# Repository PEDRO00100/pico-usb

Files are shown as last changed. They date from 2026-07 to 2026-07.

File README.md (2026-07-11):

> [!WARNING]
> ### ⚠️ LEGAL DISCLAIMER & TERMS OF USE
> 
> This hardware device, firmware, and its accompanying software suite are developed and provided **strictly for educational purposes, authorized laboratory environments, and professional security auditing.**
> 
> By building, accessing, or utilizing this tool, you acknowledge and agree to the following:
> 
> * **Authorized Use Only:** You must obtain explicit, written consent from the infrastructure or system owner before engaging in any security testing, payload injection, or assessment.
> * **No Liability:** The creators, contributors, and maintainers of this project assume **absolute no liability** and are not responsible for any direct or indirect damage, data loss, misuse, or illegal activities resulting from the deployment of this device.
> * **End-User Responsibility:** It is solely your responsibility to ensure compliance with all applicable local, state, and federal laws. Any use of this tool for malicious intent, unauthorized access, or covert data exfiltration is strictly prohibited.

## ⚙️ System Architecture & Operation

This project is a hardware-based security auditing and penetration testing tool (HID Injection Engine) built around the **RP2040** microcontroller. Unlike traditional USB injection scripts that require hardcoding and recompiling firmware for every assessment, this device operates as an autonomous, dynamic execution engine. It reads attack scripts directly from an external MicroSD card and allows instant, on-the-fly selection of up to 16 different payloads via hardware switching.

---

### 1. Hardware & Peripheral Mapping

The PCB layout is engineered for signal integrity, prioritizing short trace lengths for high-speed SPI bus lines while keeping digital control switches isolated. The GPIO pin assignment on the RP2040 is structured as follows:

| Physical Peripheral | RP2040 Pin | System Function / Role | Electrical Logic |
| :--- | :---: | :--- | :--- |
| **Setup Mode Switch (`GP0/DEV`)** | `GP0` | Toggles between Development Mode & Attack Mode | Internal Pull-Up (`GND = Dev`) |
| **DIP Switch (Bit 0 - LSB)** | `GP2` | Binary Payload Selector (`payload1Pin` / `SWD-1`) | Active-Low (`GND = 1`) |
| **DIP Switch (Bit 1)** | `GP3` | Binary Payload Selector (`payload2Pin` / `SWD-2`) | Active-Low (`GND = 1`) |
| **DIP Switch (Bit 2)** | `GP4` | Binary Payload Selector (`payload3Pin` / `SWD-3`) | Active-Low (`GND = 1`) |
| **DIP Switch (Bit 3 - MSB)** | `GP5` | Binary Payload Selector (`payload4Pin` / `SWD-4`) | Active-Low (`GND = 1`) |
| **MicroSD SPI (MISO)** | `GP16` | Data receive from external storage | SPI0 Bus |
| **MicroSD SPI (CS)** | `GP17` | Chip Select / SD card activation | Digital Output |
| **MicroSD SPI (SCK)** | `GP18` | Bus clock synchronization | SPI0 Bus |
| **MicroSD SPI (MOSI)** | `GP19` | Data transmit to external storage | SPI0 Bus |

*(Note: Additional GPIO pins such as `GP22` are routed on the PCB layout for secondary applications or future expansion, but are omitted from active execution loops to streamline automated payload delivery).*

#### 🔘 Onboard Physical Control Buttons
The device incorporates three dedicated tactile buttons for system management and firmware operations:
* **`BOOTSEL` Button:** Connected directly to the RP2040 bootrom interface. Holding this button while plugging the device into a host forces entry into USB Mass Storage bootloader mode for flashing or updating the core CircuitPython firmware (`.uf2` files).
* **`RUN` / `RST` Button:** Triggers a hard electrical reset of the RP2040 microcontroller without needing to physically unplug the USB connector, enabling rapid rebooting after switching payloads.
* **`DEV MODE` Button (`GP0`):** Pulls `GP0` to ground (`GND`). When engaged during boot, it prevents automated payload execution and mounts the internal `CIRCUITPY` drive for safe script editing.

#### 🔌 Dual-Head USB Interface & Protection
The hardware features a versatile **Dual-Head USB architecture**, integrating both **USB-A** and **USB-C** connectors directly onto the PCB edge. This allows native insertion into legacy desktops, modern laptops, servers, and mobile devices without requiring external adapters. 
* **ESD Protection:** The data lines (`D+` / `D-`) include onboard electrical protections and transient voltage suppression to safeguard the microcontroller against static discharges during rapid field insertion.
* **⚠️ Critical Safety Rule:** The dual connectors share the same internal USB data bus. **Never connect both USB-A and USB-C ports simultaneously to two different host devices or power sources**, as this could cause bus contention or electrical back-feeding.

---

### 2. Binary Payload Selector (4-Bit DIP Switch)

To eliminate the need for reprogramming the device between different engagement scenarios, the board features an onboard 4-position DIP switch (`A6H-4101`) operating on **pure binary decoding**.

Each switch pin is configured with internal pull-up resistors (Active-Low logic). Moving a switch to the **ON** position bridges the circuit to Ground (`GND`), which the firmware decodes as a logical `1` for that specific bit position.

```text
Bit 3 (MSB)   Bit 2       Bit 1       Bit 0 (LSB)
  [GP5]       [GP4]       [GP3]       [GP2]
  Value: 8    Value: 4    Value: 2    Value: 1

```

* **Combination `0000` (All OFF):** Executes the default script located at `/sd/payload.dd`.
* **Combinations `0001` through `1111` (1 to 15):** Sums the active bit values in powers of 2 and dynamically routes execution to the numbered script on the MicroSD card (from `/sd/payload1.dd` up to `/sd/payload15.dd`).

---

### 3. Operating Modes & USB Stealth Spoofing

The USB enumeration profile is strictly managed by `boot.py` **before** the target operating system (Windows, macOS, or Linux) initializes the peripheral. The operating mode is governed by the state of the `GP0` tactile button/switch:

#### 🟢 Development Mode (`GP0` connected to GND)

* **Purpose:** Script editing, live debugging, and system maintenance.
* **USB Profile:** Habilitates standard USB Mass Storage (exposing the internal `CIRCUITPY` drive), Serial CDC (REPL console), and HID keyboard interfaces. Automated attack execution is safely bypassed.

#### 🔴 Attack / Stealth Mode (`GP0` floating / Unpressed)

* **Purpose:** Active field auditing and Endpoint Detection & Response (EDR / DLP) evasion.
* **USB Profile:** The firmware executes `storage.disable_usb_drive()`, completely hiding internal Flash memory from the host OS and disabling Serial/MIDI endpoints (`usb_cdc.disable()`, `usb_midi.disable()`).
* **Identity Spoofing:** To prevent triggering vendor-specific blocklists while adhering to safe open-source distribution standards (BYOC - *Bring Your Own Configuration*), the device overrides its hardware descriptors using the open community VID **`0x1209`** (pid.codes) and generic keyboard PID **`0x0001`**:

```python
# Hardware descriptor override defined in boot.py
supervisor.set_usb_identification(
    vid=0x1209,         # Open-Source Community VID (pid.codes)
    pid=0x0001,         # Generic Keyboard PID
    manufacturer="Generic",
    product="USB Keyboard"
)

```

> ⚠️ **Tactical Advantage:** When plugged into a host system in Attack Mode, the operating system **strictly enumerates a generic HID USB Keyboard**. No storage drives are mounted, no COM ports appear in Device Manager, and no Raspberry Pi / Adafruit hardware signatures are exposed.

---

### 4. Asynchronous Execution Engine & Resilience

The core execution engine (`code.py`) is built around asynchronous event loops (`asyncio`). This allows the microcontroller to handle concurrent background tasks—such as button debouncing, filesystem polling, and monitoring host keyboard lock LEDs (Caps/Num/Scroll Lock) for data exfiltration—without causing latency or blocking keystroke injection.

To guarantee field reliability and prevent kernel panics during live deployments, the firmware implements multiple defensive architecture layers:

1. **Zero-RAM Allocation Filesystem Polling:** To check for the presence of payload files on the MicroSD card without fragmenting the microcontroller's limited heap memory, the engine avoids memory-heavy directory listings (`os.listdir()`). Instead, it performs direct, low-overhead FAT32 metadata queries using `os.stat()`.
2. **3-Tier Fallback Routing:** If an indexed script cannot be read, the execution pipeline gracefully degrades through three safety tiers to ensure the assessment does not fail silently:
* *Tier 1:* Attempts to execute the exact binary path selected by the DIP switch (e.g., `/sd/payload5.dd`).
* *Tier 2:* If the target file is missing, it falls back automatically to the standard default script (`/sd/payload.dd`).
* *Tier 3:* If the default script is also missing, it performs an emergency scan of the MicroSD card root and executes the first available `.dd` payload found.

3. **Hardware Kill-Switch:** During the boot sequence, if the engine detects a file named `loot.bin` in the root directory, it immediately aborts all keystroke injection routines to prevent accidental exfiltration overrides or execution loops.

## 💾 Firmware & Software Installation Guide

Setting up the device is divided into two straightforward phases: flashing the base interpreter (CircuitPython) and loading the attack and decoding engine. Once this process is complete, the microcontroller's execution logic will be permanently configured.

---

### Step 1: Installing the Core Engine (CircuitPython)

To enable the RP2040 microcontroller to interpret attack scripts in real time, you must install the base CircuitPython firmware:

1. **Bootloader Mode:** Press and hold the onboard **`BOOTSEL`** physical button while plugging the USB cable into your computer.
2. **RPI-RP2 Drive:** Release the button once plugged in. Your operating system will automatically mount a mass storage drive named `RPI-RP2`.
3. **Flashing:** Download the latest official release of **CircuitPython 10.x** (`.uf2` file format) for the Raspberry Pi Pico / RP2040 and drag the file directly into the `RPI-RP2` drive.
4. **Automatic Reboot:** Once the copy completes, the drive will automatically eject, and the microcontroller will reboot, creating a new flash drive named **`CIRCUITPY`**.

---

### Step 2: Loading the Attack Engine & Dependencies

Once the `CIRCUITPY` drive is available, you must transfer the core operating logic and hardware libraries. Navigate to the `Software/` directory within this repository, which contains the exact system package:

```text
Software/
├── boot.py             # Hardware USB Profile & Stealth Spoofing Manager
├── boot_out.txt        # System boot log (Auto-generated by CircuitPython)
├── code.py             # Asynchronous Core Kernel & Execution Loop
├── duckyinpython.py    # DuckyScript Parser & Payload Execution Engine
├── lib/                # Required CircuitPython libraries (HID, Debouncer, etc.)
├── LICENSE             # GPLv2 License
├── pins.py             # Hardware GPIO Pin Mapping & DIP Switch Config
├── sd/                 # Example payload directory (For external MicroSD card)
└── settings.toml       # Runtime configuration file

```

#### 📦 File Transfer Protocol:

1. **Internal Flash (`CIRCUITPY` drive):**
* Select and copy all core Python scripts (`boot.py`, `code.py`, `duckyinpython.py`, `pins.py`, `settings.toml`, and `LICENSE`).
* **⚠️ CRITICAL - The `lib/` folder:** You **must** copy the entire **`lib/`** directory into the root of the `CIRCUITPY` drive. This folder contains essential drivers (`adafruit_hid`, `adafruit_debouncer`, etc.) required for keystroke injection and tactile button reading.
* *(Note: You can ignore `boot_out.txt`, as the microcontroller will automatically regenerate this log file on its next boot).*

2. **External Storage (MicroSD Card):**
* Take the contents inside the **`sd/`** folder (e.g., your `.dd` payload files) and copy them directly to the root of your FAT32-formatted **MicroSD card**.
* Insert the MicroSD card into the onboard SPI slot (`J3`). When the RP2040 boots, `code.py` will automatically mount this physical card at the `/sd` system path.

---

### Step 3: Access Management & Safe Mode (Critical!)

As soon as the system files are copied over, `boot.py` will take absolute control of the board's USB interfaces on every subsequent boot. It is crucial to understand the following tactical behavior before unplugging the cable:

> 🚨 **AUTOMATIC INJECTION WARNING:**
> From this moment forward, **every time you plug the device into a USB port normally, it will boot in Attack Mode (Stealth Mode)**. This means the `CIRCUITPY` drive will completely disappear from your operating system, and the payload selected via the DIP switch on the MicroSD card **will execute automatically and immediately**.

#### 🛠️ How to re-access the `CIRCUITPY` drive to edit code?

To prevent the attack script from triggering and to mount the internal storage drive back onto your computer (e.g., to debug code or update core scripts), you must engage the hardware safety override:

1. **Press and hold the `DEV MODE` (`GP0`) button** on the board.
2. While holding the button down, **plug the USB cable** into your computer.
3. Once plugged in, you can safely release the button.
4. **Result:** The microcontroller detects the ground connection on pin `GP0`, aborts automated payload execution, and safely exposes the `CIRCUITPY` drive and Serial REPL console on your screen in safe development mode.

## 🛠️ Hardware Compatibility & DIY Protoboard Build

While this project features a custom-designed, dedicated PCB with integrated dual-head USB connectors and ESD protection, the core software suite is **100% compatible with standard, off-the-shelf Raspberry Pi Pico** boards (or any generic RP2040 development board running CircuitPython).

If you are prototyping on a breadboard or building a custom DIY injection tool using an original Raspberry Pi Pico, you can deploy this firmware without modifying a single line of code. You simply need to manually wire the external modules according to the hardware mapping defined in `pins.py`:

### 📌 DIY Wiring Checklist for Standard Pico:
* **MicroSD Card Module:** Wire a 3.3V SPI MicroSD breakout board directly to the RP2040's **SPI0 bus** (`MISO` -> `GP16`, `CS` -> `GP17`, `SCK` -> `GP18`, and `MOSI` -> `GP19`).
* **4-Bit Binary DIP Switch:** Connect four mechanical switches (or simple jumper wires) between ground (`GND`) and pins **`GP2`**, **`GP3`**, **`GP4`**, and **`GP5`**. When closed (grounded), the internal pull-up resistor drops to `0V`, which the software decodes as an active binary `1`.
* **Development Mode Safety Jumper (`GP0`):** You **must** wire a tactile button or jumper wire between **`GP0`** and **`GND`**. This is critical: without this physical override, an off-the-shelf Pico will permanently boot in Stealth Attack Mode, hiding the USB drive and locking you out of the REPL console.

---

## 📂 MicroSD Payload Structure & Binary Mapping

The execution engine searches the root directory of the FAT32-formatted MicroSD card for standard DuckyScript (`.dd`) payload files. To utilize the hardware DIP switch, name your scripts following this exact binary convention:

| DIP Switch State (`SW4` -> `SW1`) | Binary Value | Target Payload Path | Description / Engagement Use Case |
| :---: | :---: | :--- | :--- |
| `OFF` · `OFF` · `OFF` · `OFF` | `0000` (0) | `/sd/payload.dd` | Default fallback / Standard assessment payload |
| `OFF` · `OFF` · `OFF` · `ON`  | `0001` (1) | `/sd/payload1.dd` | Quick reconnaissance / System info enumeration |
| `OFF` · `OFF` · `ON`  · `OFF` | `0010` (2) | `/sd/payload2.dd` | Remote access staging / Reverse shell |
| `...` · `...` · `...` · `...` | `1 to 14`  | `/sd/payload3.dd` to `14.dd` | Custom specialized audit scripts |
| `ON`  · `ON`  · `ON`  · `ON`  | `1111` (15)| `/sd/payload15.dd`| Emergency cleanup / Anti-forensic routine |

> 💡 **Tactical Fallback Note:** If you dial a specific binary combination on the DIP switch (e.g., index `5`) but forget to load `/sd/payload5.dd` onto the MicroSD card, the asynchronous engine will not crash. It automatically downgrades to Tier-2 fallback and executes `/sd/payload.dd`, guaranteeing that your field engagement never fails silently.

---

## 📸 Board Designs & Renders

3D renders and PCB layer routing for the **Pico-USB** board.

<table align="center">
  <tr>
    <td align="center">
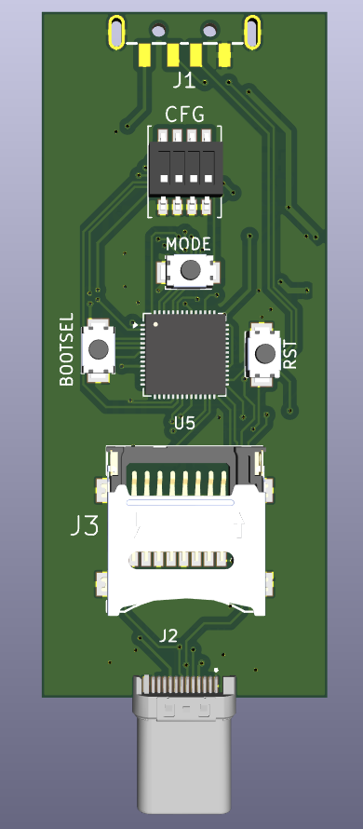
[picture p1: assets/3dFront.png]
3D Front View
      <br/>
      <sub><b>3D Front</b></sub>
    </td>
    <td align="center">
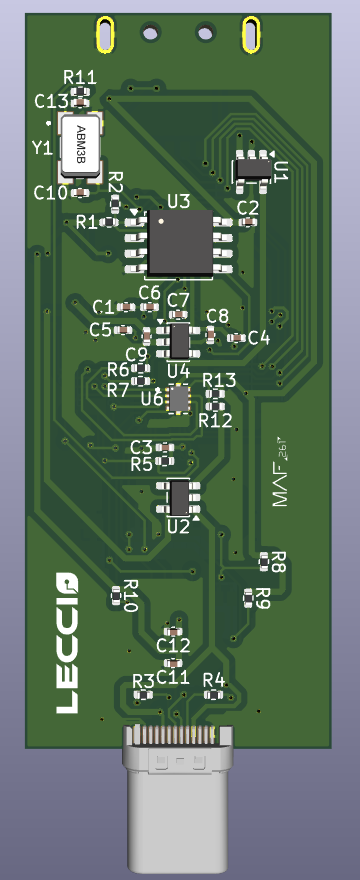
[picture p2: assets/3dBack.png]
3D Back View
      <br/>
      <sub><b>3D Back</b></sub>
    </td>
    <td align="center">
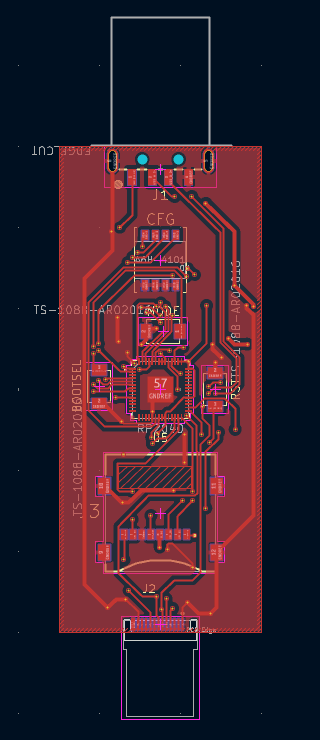
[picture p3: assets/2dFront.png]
2D Front Routing (F.Cu)
      <br/>
      <sub><b>2D F.Cu</b></sub>
    </td>
    <td align="center">
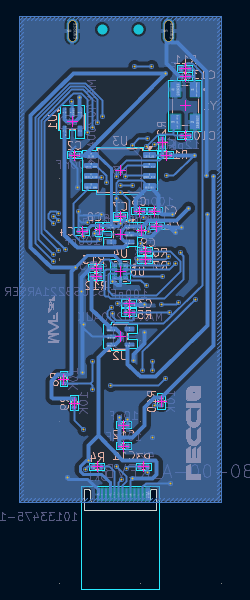
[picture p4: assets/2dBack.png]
2D Back Routing (B.Cu)
      <br/>
      <sub><b>2D B.Cu</b></sub>
    </td>
  </tr>
</table>

---

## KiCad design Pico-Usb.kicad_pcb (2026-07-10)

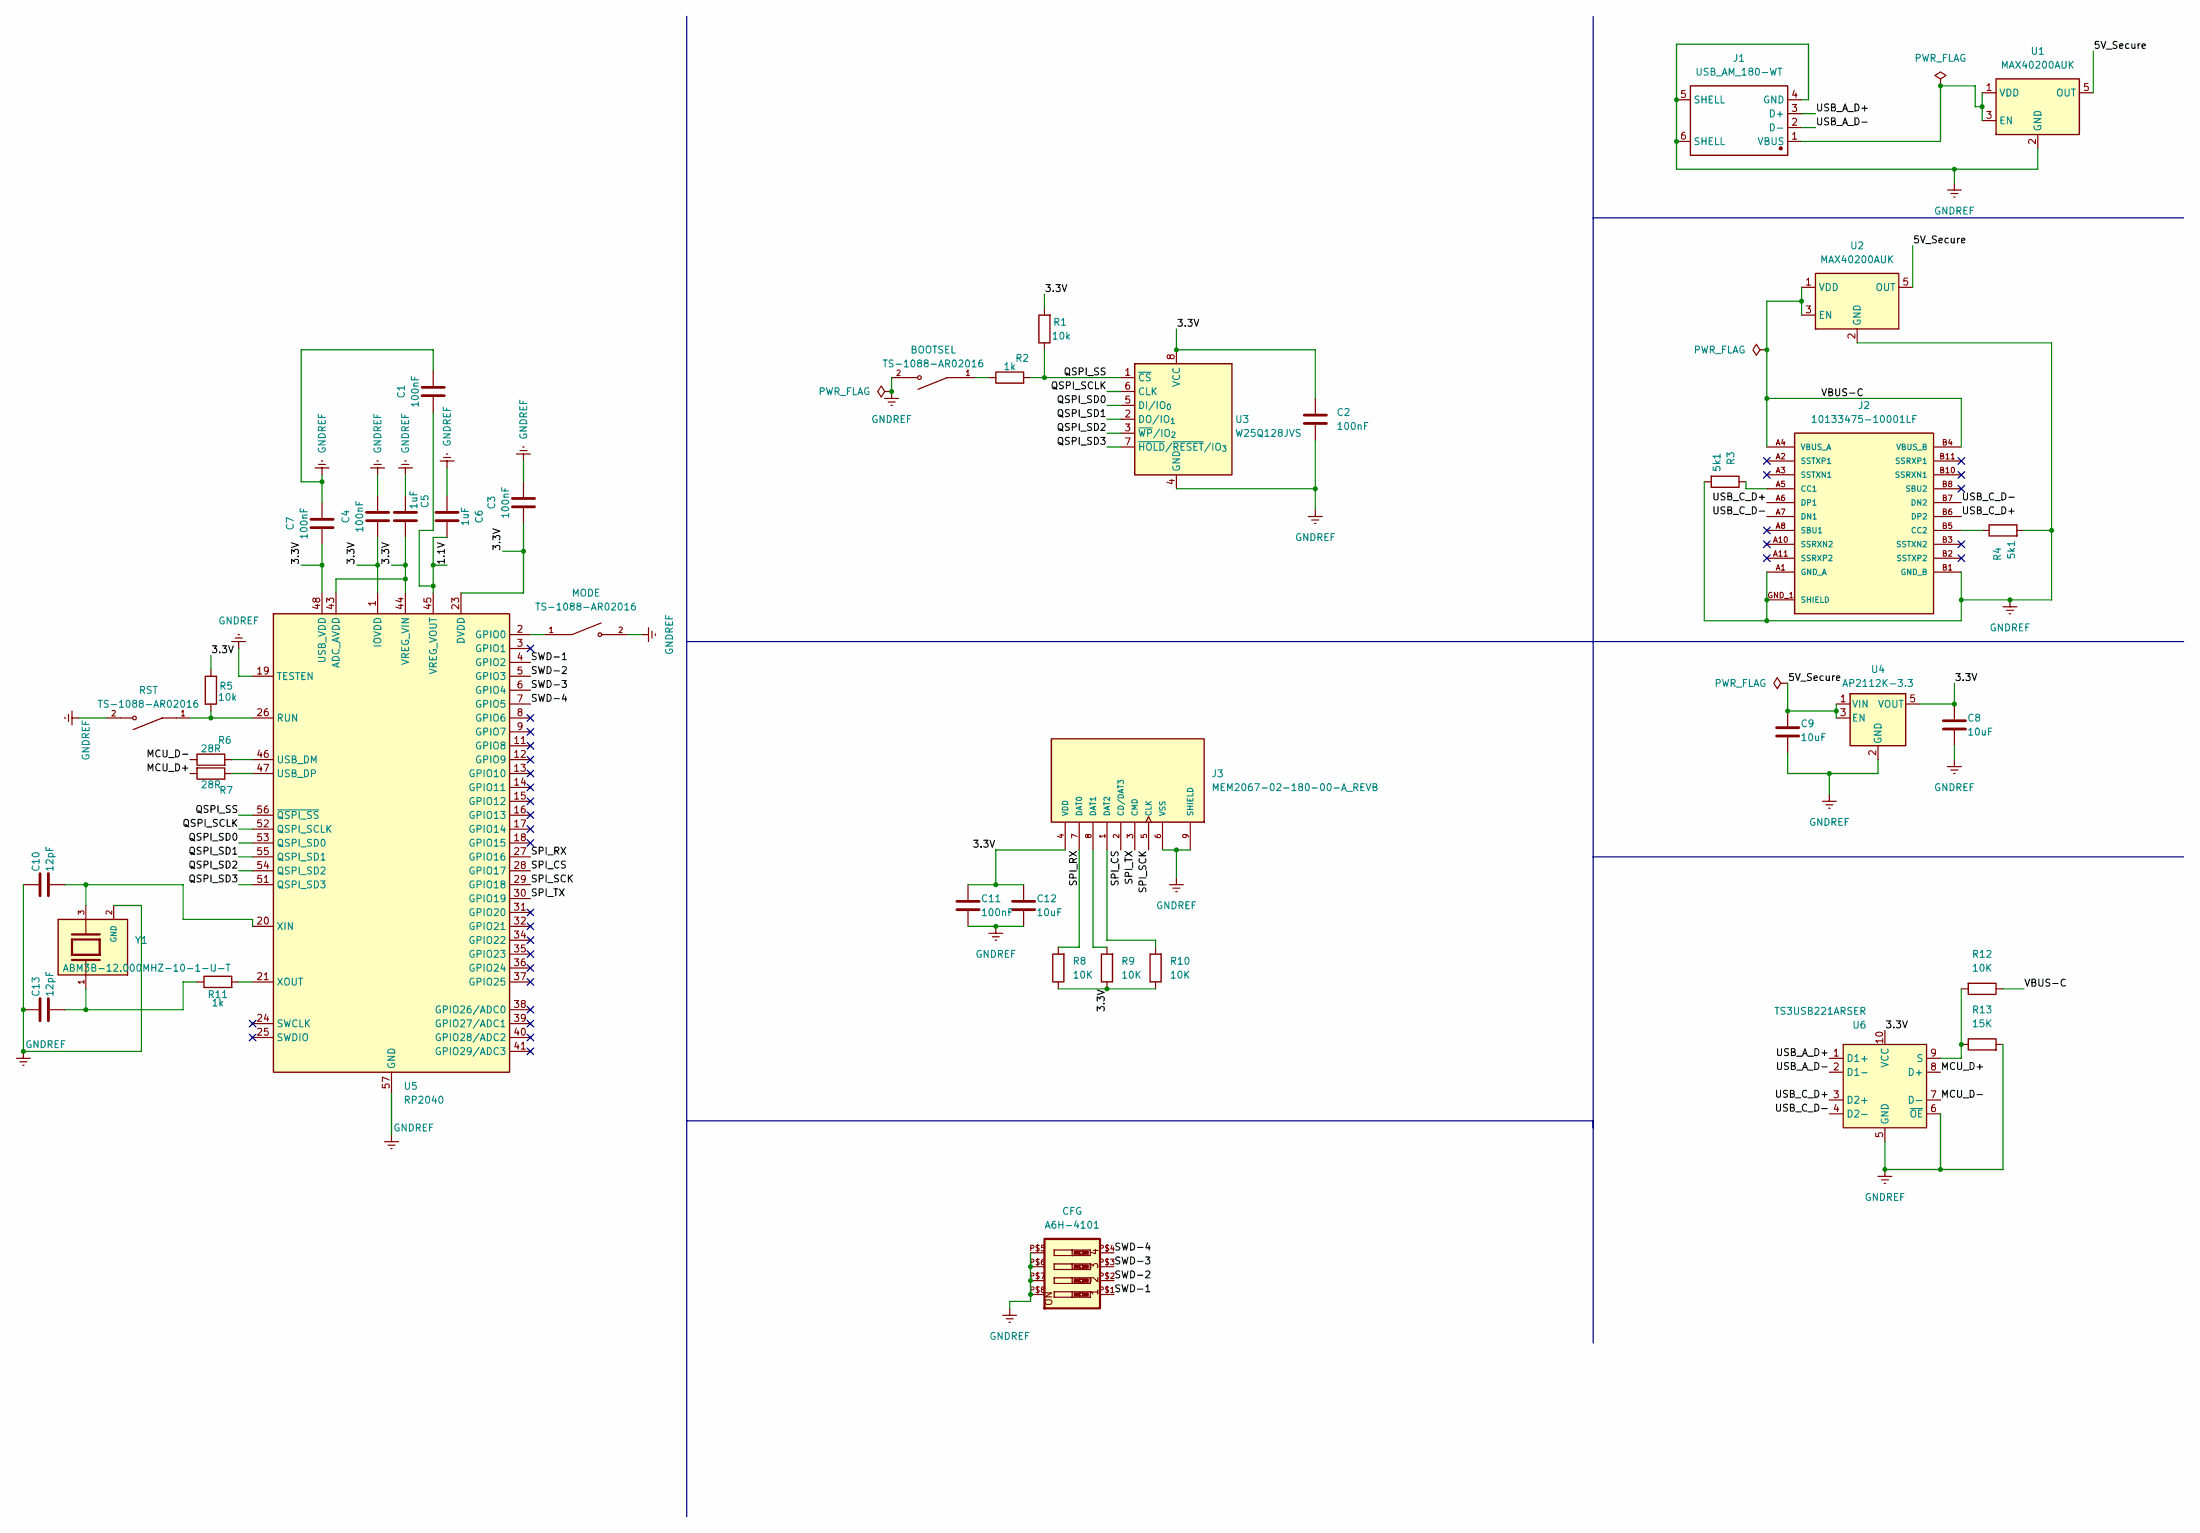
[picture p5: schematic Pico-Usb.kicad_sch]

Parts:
BOOTSEL: TS-1088-AR02016; SW_TS-1088-AR02016; PARTREV N/A
C1, C2, C3, C4, C7, C11: 100nF; C_0402_1005Metric
C5, C6: 1uF; C_0402_1005Metric
C8, C9, C12: 10uF; C_0402_1005Metric
C10, C13: 12pF; C_0402_1005Metric
CFG: A6H-4101; A6H-410X
J1: USB_AM_180-WT; USB-AM-180-WT
J2: 10133475-10001LF; Amphenol_USBC_Plug; PARTREV C
J3: MEM2067-02-180-00-A_REVB; GCT_MEM2067-02-180-00-A_REVB
MODE: TS-1088-AR02016; SW_TS-1088-AR02016; PARTREV N/A
R1, R5: 10k; R_0402_1005Metric
R2, R11: 1k; R_0402_1005Metric
R3, R4: 5k1; R_0402_1005Metric
R6, R7: 28R; R_0402_1005Metric
R8, R9, R10, R12: 10K; R_0402_1005Metric
R13: 15K; R_0402_1005Metric
RST: TS-1088-AR02016; SW_TS-1088-AR02016; PARTREV N/A
U1, U2: MAX40200AUK; SOT-23-5
U3: W25Q128JVS; SOIC-8_5.3x5.3mm_P1.27mm
U4: AP2112K-3.3; SOT-23-5
U5: RP2040; QFN-56-1EP_7x7mm_P0.4mm_EP3.2x3.2mm
U6: TS3USB221ARSER; TS3USB221
Y1: ABM3B-12.000MHZ-10-1-U-T; XTAL_ABM3B-12.000MHZ-10-1-U-T; PARTREV 08.25.15

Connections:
/1.1V: C1.1, C6.1, U5.45 (VREG_VOUT)
/3.3V: C2.1, C3.1, C4.1, C5.1, C7.1, C8.1, C11.1, C12.1, J3.4 (VDD), R1.2, R5.1, R8.1, R9.1, R10.1, U3.8 (VCC), U4.5 (VOUT), U5.1 (IOVDD), U5.10 (IOVDD), U5.22 (IOVDD), U5.23 (DVDD), U5.33 (IOVDD), U5.42 (IOVDD), U5.43 (ADC_AVDD), U5.44 (VREG_VIN), U5.48 (USB_VDD), U5.49 (IOVDD), U5.50 (DVDD), U6.10 (VCC)
/5V_Secure: C9.1, U1.5 (OUT), U2.5 (OUT), U4.1 (VIN), U4.3 (EN)
/MCU_D+: R7.2, U6.8 (D+)
/MCU_D-: R6.1, U6.7 (D-)
/QSPI_SCLK: U3.6 (CLK), U5.52 (QSPI_SCLK)
/QSPI_SD0: U3.5 (DI/IO_{0}), U5.53 (QSPI_SD0)
/QSPI_SD1: U3.2 (DO/IO_{1}), U5.55 (QSPI_SD1)
/QSPI_SD2: U3.3 (~WP/IO_{2}), U5.54 (QSPI_SD2)
/QSPI_SD3: U3.7 (~HOLD/~RESET/IO_{3}), U5.51 (QSPI_SD3)
/QSPI_SS: R1.1, R2.2, U3.1 (~CS), U5.56 (~QSPI_SS)
/SPI_CS: J3.2 (CD/DAT3), U5.28 (GPIO17)
/SPI_RX: J3.7 (DAT0), R8.2, U5.27 (GPIO16)
/SPI_SCK: J3.5 (CLK), U5.29 (GPIO18)
/SPI_TX: J3.3 (CMD), U5.30 (GPIO19)
/SWD-1: CFG.P$1, U5.4 (GPIO2)
/SWD-2: CFG.P$2, U5.5 (GPIO3)
/SWD-3: CFG.P$3, U5.6 (GPIO4)
/SWD-4: CFG.P$4, U5.7 (GPIO5)
/USB_A_D+: J1.3 (D+), U6.1 (D1+)
/USB_A_D-: J1.2 (D-), U6.2 (D1-)
/USB_C_D+: J2.A6 (DP1), J2.B6 (DP2), U6.3 (D2+)
/USB_C_D-: J2.A7 (DN1), J2.B7 (DN2), U6.4 (D2-)
GNDREF: BOOTSEL.2, C1.2, C2.2, C3.2, C4.2, C5.2, C6.2, C7.2, C8.2, C9.2, C10.1, C11.2, C12.2, C13.1, CFG.P$5, CFG.P$6, CFG.P$7, CFG.P$8, J1.4 (GND), J1.5 (SHELL), J1.6 (SHELL), J2.A1 (GND_A), J2.A12 (GND_A), J2.B1 (GND_B), J2.B12 (GND_B), J2.GND_1 (SHIELD), J2.GND_2 (SHIELD), J3.6 (VSS), J3.9 (SHIELD), J3.10 (SHIELD), J3.11 (SHIELD), J3.12 (SHIELD), MODE.2, R3.2, R4.2, R13.2, RST.2, U1.2 (GND), U2.2 (GND), U3.4 (GND), U4.2 (GND), U5.19 (TESTEN), U5.57 (GND), U6.5 (GND), U6.6 (~OE), Y1.2 (GND), Y1.4 (GND)
unnamed: BOOTSEL.1, R2.1
unnamed: C13.2, R11.1, Y1.1
unnamed: J2.A5 (CC1), R3.1
unnamed: J2.B5 (CC2), R4.1
unnamed: J3.8 (DAT1), R9.2
unnamed: J3.1 (DAT2), R10.2
unnamed: J1.1 (VBUS), U1.1 (VDD), U1.3 (EN)
unnamed: MODE.1, U5.2 (GPIO0)
unnamed: R5.2, RST.1, U5.26 (RUN)
unnamed: R6.2, U5.46 (USB_DM)
unnamed: R7.1, U5.47 (USB_DP)
unnamed: C10.2, U5.20 (XIN), Y1.3
unnamed: R11.2, U5.21 (XOUT)
unnamed: R12.2, R13.1, U6.9 (S)
VBUS_A: J2.A4 (VBUS_A), J2.A9 (VBUS_A), J2.B4 (VBUS_B), J2.B9 (VBUS_B), R12.1, U2.1 (VDD), U2.3 (EN)

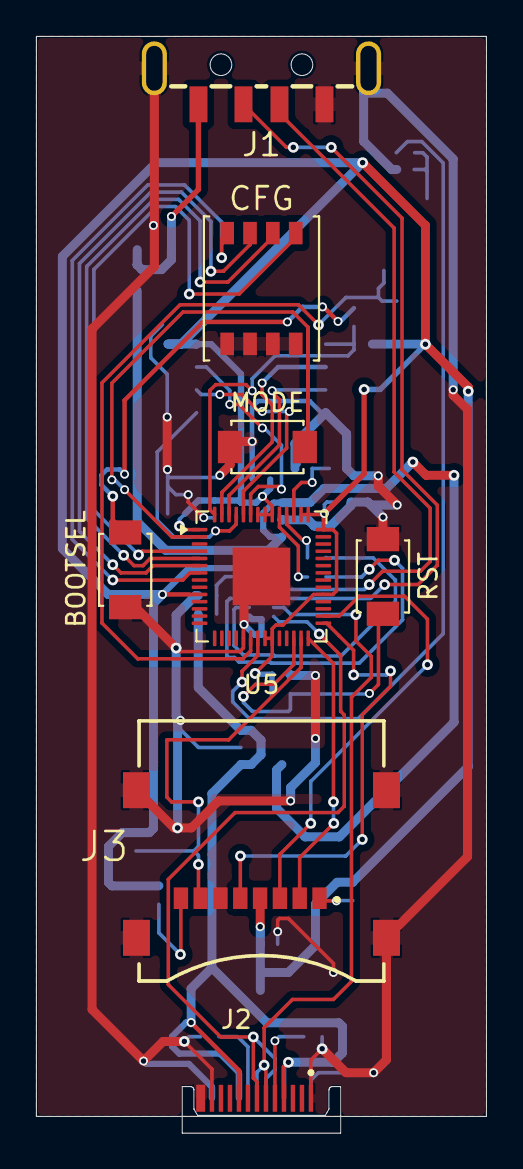
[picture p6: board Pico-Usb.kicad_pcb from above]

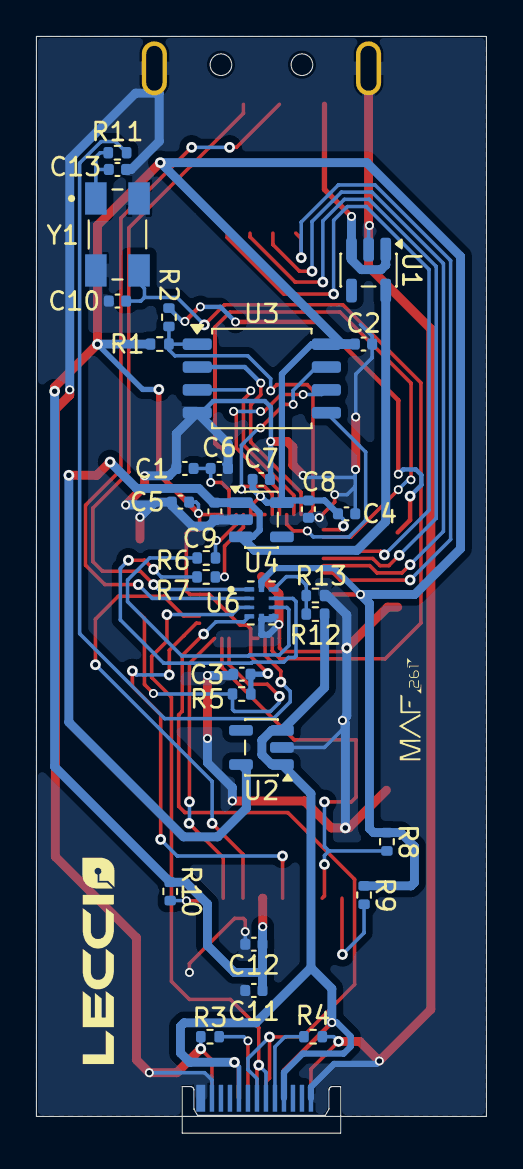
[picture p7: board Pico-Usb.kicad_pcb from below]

Board: 2 copper layers, 25.0 x 60.9 mm, 40 parts (32 on the bottom side), 39 nets.

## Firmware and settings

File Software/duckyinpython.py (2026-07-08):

# License: GPLv2.0
# Copyright (c) 2026  Dave Bailey
# Author: Dave Bailey (dbisu, @daveisu)
#
# Modified and adapted by:
# Copyright (c) 2026  Pedro Pacheco
# Copyright (c) 2026  Nahum Silvestre Martinez
# - RP2040 hardware adaptation and system modifications.
#
# TODO: ADD support for the following:
# Add jitter
# Add LED functionality
import os
import re
import time
import random
import digitalio
from digitalio import DigitalInOut, Pull
from adafruit_debouncer import Debouncer
import board
from board import *
import asyncio
import usb_hid
from adafruit_hid.keyboard import Keyboard
from adafruit_hid.consumer_control import ConsumerControl
from adafruit_hid.consumer_control_code import ConsumerControlCode
from pins import *

# comment out these lines for non_US keyboards
from adafruit_hid.keyboard_layout_us import KeyboardLayoutUS as KeyboardLayout
from adafruit_hid.keycode import Keycode

# uncomment these lines for non_US keyboards
# replace LANG with appropriate language
#from keyboard_layout_win_LANG import KeyboardLayout as KeyboardLayout
#from keycode_win_LANG import Keycode

def _capsOn():
    return kbd.led_on(Keyboard.LED_CAPS_LOCK)

def _numOn():
    return kbd.led_on(Keyboard.LED_NUM_LOCK)

def _scrollOn():
    return kbd.led_on(Keyboard.LED_SCROLL_LOCK)

def pressLock(key):
    kbd.press(key)
    kbd.release(key)

def SaveKeyboardLedState():
    variables["$_INITIAL_SCROLLLOCK"] = _scrollOn()
    variables["$_INITIAL_NUMLOCK"] = _numOn()
    variables   ["$_INITIAL_CAPSLOCK"] = _capsOn()


def RestoreKeyboardLedState():
    if(variables["$_INITIAL_CAPSLOCK"] != _capsOn()):
        pressLock(Keycode.CAPS_LOCK)
    if(variables["$_INITIAL_NUMLOCK"] != _numOn()):
        pressLock(Keycode.NUM_LOCK)
    if(variables["$_INITIAL_SCROLLLOCK"] != _scrollOn()):
        pressLock(Keycode.SCROLL_LOCK)

duckyKeys = {
    'WINDOWS': Keycode.GUI, 'RWINDOWS': Keycode.RIGHT_GUI, 'GUI': Keycode.GUI, 'RGUI': Keycode.RIGHT_GUI, 'COMMAND': Keycode.GUI, 'RCOMMAND': Keycode.RIGHT_GUI,
    'APP': Keycode.APPLICATION, 'MENU': Keycode.APPLICATION, 'SHIFT': Keycode.SHIFT, 'RSHIFT': Keycode.RIGHT_SHIFT,
    'ALT': Keycode.ALT, 'RALT': Keycode.RIGHT_ALT, 'OPTION': Keycode.ALT, 'ROPTION': Keycode.RIGHT_ALT, 'CONTROL': Keycode.CONTROL, 'CTRL': Keycode.CONTROL, 'RCTRL': Keycode.RIGHT_CONTROL,
    'DOWNARROW': Keycode.DOWN_ARROW, 'DOWN': Keycode.DOWN_ARROW, 'LEFTARROW': Keycode.LEFT_ARROW,
    'LEFT': Keycode.LEFT_ARROW, 'RIGHTARROW': Keycode.RIGHT_ARROW, 'RIGHT': Keycode.RIGHT_ARROW,
    'UPARROW': Keycode.UP_ARROW, 'UP': Keycode.UP_ARROW, 'BREAK': Keycode.PAUSE,
    'PAUSE': Keycode.PAUSE, 'CAPSLOCK': Keycode.CAPS_LOCK, 'DELETE': Keycode.DELETE,
    'END': Keycode.END, 'ESC': Keycode.ESCAPE, 'ESCAPE': Keycode.ESCAPE, 'HOME': Keycode.HOME,
    'INSERT': Keycode.INSERT, 'NUMLOCK': Keycode.KEYPAD_NUMLOCK, 'PAGEUP': Keycode.PAGE_UP,
    'PAGEDOWN': Keycode.PAGE_DOWN, 'PRINTSCREEN': Keycode.PRINT_SCREEN, 'ENTER': Keycode.ENTER,
    'SCROLLLOCK': Keycode.SCROLL_LOCK, 'SPACE': Keycode.SPACE, 'TAB': Keycode.TAB,
    'BACKSPACE': Keycode.BACKSPACE,
    'A': Keycode.A, 'B': Keycode.B, 'C': Keycode.C, 'D': Keycode.D, 'E': Keycode.E,
    'F': Keycode.F, 'G': Keycode.G, 'H': Keycode.H, 'I': Keycode.I, 'J': Keycode.J,
    'K': Keycode.K, 'L': Keycode.L, 'M': Keycode.M, 'N': Keycode.N, 'O': Keycode.O,
    'P': Keycode.P, 'Q': Keycode.Q, 'R': Keycode.R, 'S': Keycode.S, 'T': Keycode.T,
    'U': Keycode.U, 'V': Keycode.V, 'W': Keycode.W, 'X': Keycode.X, 'Y': Keycode.Y,
    'Z': Keycode.Z, 'F1': Keycode.F1, 'F2': Keycode.F2, 'F3': Keycode.F3,
    'F4': Keycode.F4, 'F5': Keycode.F5, 'F6': Keycode.F6, 'F7': Keycode.F7,
    'F8': Keycode.F8, 'F9': Keycode.F9, 'F10': Keycode.F10, 'F11': Keycode.F11,
    'F12': Keycode.F12, 'F13': Keycode.F13, 'F14': Keycode.F14, 'F15': Keycode.F15,
    'F16': Keycode.F16, 'F17': Keycode.F17, 'F18': Keycode.F18, 'F19': Keycode.F19,
    'F20': Keycode.F20, 'F21': Keycode.F21, 'F22': Keycode.F22, 'F23': Keycode.F23,
    'F24': Keycode.F24
}
duckyConsumerKeys = {
    'MK_VOLUP': ConsumerControlCode.VOLUME_INCREMENT, 'MK_VOLDOWN': ConsumerControlCode.VOLUME_DECREMENT, 'MK_MUTE': ConsumerControlCode.MUTE,
    'MK_NEXT': ConsumerControlCode.SCAN_NEXT_TRACK, 'MK_PREV': ConsumerControlCode.SCAN_PREVIOUS_TRACK,
    'MK_PP': ConsumerControlCode.PLAY_PAUSE, 'MK_STOP': ConsumerControlCode.STOP
}

variables = {"$_RANDOM_MIN": 0, "$_RANDOM_MAX": 65535,"$_EXFIL_MODE_ENABLED": False,"$_EXFIL_LEDS_ENABLED": False,"$_INITIAL_SCROLLLOCK": False, "$_INITIAL_NUMLOCK": False, "$_INITIAL_CAPSLOCK": False}
internalVariables = {"$_CAPSLOCK_ON": _capsOn, "$_NUMLOCK_ON": _numOn, "$_SCROLLLOCK_ON": _scrollOn}
defines = {}
functions = {}

letters = "abcdefghijklmnopqrstuvwxyz"
numbers = "0123456789"
specialChars = "!@#$%^&*()"
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

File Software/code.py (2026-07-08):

# License: GPLv2.0
# Copyright (c) 2026 Dave Bailey
# Author: Dave Bailey (dbisu, @daveisu)
# Refactored: 2026 - Optimized Async Polling & Zero-RAM Allocations

import supervisor
import os
import pwmio
import time
import digitalio
import board
import busio
import storage

from duckyinpython import *

def log(level: str, msg: str):
    print(f"[{level}] {msg}")

log("INFO", "Initializing Hardware Execution Engine")
time.sleep(0.15)
supervisor.runtime.autoreload = False

# MicroSD Hardware Initialization
sd_mounted = False
try:
    log("INFO", "Configuring SPI bus (SCK:GP18, MOSI:GP19, MISO:GP16, CS:GP17)")
    spi = busio.SPI(clock=board.GP18, MOSI=board.GP19, MISO=board.GP16)
    
    try:
        import sdcardio
        sdcard = sdcardio.SDCard(spi, board.GP17)
        log("DEBUG", "SD mounted via sdcardio (Native C driver)")
    except ImportError:
        import adafruit_sdcard
        cs = digitalio.DigitalInOut(board.GP17)
        sdcard = adafruit_sdcard.SDCard(spi, cs)
        log("DEBUG", "SD mounted via adafruit_sdcard (Legacy driver)")

    vfs = storage.VfsFat(sdcard)
    storage.mount(vfs, "/sd")
    sd_mounted = True
    log("SUCCESS", "MicroSD mounted at /sd")
    
except Exception as e:
    log("WARN", f"SD Mount failed ({e}). Flash memory fallback active.")

led = pwmio.PWMOut(board.LED, frequency=5000, duty_cycle=0)

def file_exists_fast(path: str) -> bool:
    """Zero-RAM allocation filesystem check using FAT32 metadata."""
    try:
        os.stat(path)
        return True
    except OSError:
        return False

async def wait_for_sd_ready_async(timeout_sec=2.0, interval=0.1):
    if not sd_mounted:
        return False

    log("INFO", "Verifying SD Card filesystem indexing...")
    start_time = time.monotonic()

    while (time.monotonic() - start_time) < timeout_sec:
        if file_exists_fast("/sd"):
            log("SUCCESS", "SD Card filesystem ready.")
            return True
        await asyncio.sleep(interval)
        
    log("WARN", "SD Card filesystem indexing timeout.")
    return False

async def run_payload_on_startup():
    if getProgrammingStatus():
        log("INFO", "Dev Mode active (GP0 grounded). Halting automated execution.")
        return

    if file_exists_fast("/loot.bin") or file_exists_fast("/sd/loot.bin"):
        log("WARN", "Kill-switch 'loot.bin' detected. Aborting pipeline.")
        return

    if sd_mounted:
        await wait_for_sd_ready_async(timeout_sec=2.0, interval=0.1)

    log("INFO", "Resolving target payload via binary DIP switch...")
    payload_path = selectPayload()

    if payload_path and file_exists_fast(payload_path):
        log("SUCCESS", f"Executing payload: {payload_path}")
        await runScript(payload_path)
    else:
        log("ERROR", f"Target payload '{payload_path}' unreachable.")

async def main_loop():
    log("INFO", "Starting asynchronous kernel loop")
    tasks = [
        asyncio.create_task(blink_pico_led(led)),
        asyncio.create_task(monitor_buttons(button1)),
        asyncio.create_task(monitor_led_changes()),
        asyncio.create_task(run_payload_on_startup())
    ]
    
    try:
        await asyncio.gather(*tasks)
    except asyncio.CancelledError:
        log("WARN", "Async tasks cancelled cleanly.")
    except Exception as e:
        log("ERROR", f"Runtime exception in task execution: {e}")

try:
    asyncio.run(main_loop())
except Exception as e:
    log("FATAL", f"System halt: {e}")

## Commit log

2026-07-07 Configuración inicial de KiCad y adición de archivos base
2026-07-07 Cambie pistas de 90 grados
    [Pico-Usb.kicad_pcb]
2026-07-07 Movi capacitor
    [Pico-Usb.kicad_pcb]
2026-07-07 Mejoré el diseño
    [Pico-Usb.kicad_pcb]
2026-07-07 Corregi el posicionamiento usb y mejore un poco la distribución de las pistas
    [Pico-Usb.kicad_pcb]
2026-07-08 Elimine todas las pistas y acomode los componetes
    [Pico-Usb.kicad_pcb]
2026-07-08 Hice nuevo ruteo, checar y terminar o reiniciar por bloqueo de rutas para conexiones restantes
    [Pico-Usb.kicad_pcb]
2026-07-08 Cambie dimensiones de pistas
    [Pico-Usb.kicad_pcb]
2026-07-08 reconfigure pistas para liberar componentes
    [Pico-Usb.kicad_pcb]
2026-07-08 complete el ruteo de la memoria al rp2040
    [Pico-Usb.kicad_pcb]
2026-07-08 Termine el ruteo
    [Pico-Usb.kicad_pcb, Pico-Usb.kicad_sch]
2026-07-08 Agregue el software que va a utilizar
2026-07-08 Agregue derechos de autor
2026-07-08 Se configuro el software principal para la usb
2026-07-09 corregi la definicion de pines GP
2026-07-09 Enhance README with hardware compatibility and wiring info
    Added detailed hardware compatibility information and DIY wiring checklist for Raspberry Pi Pico, including MicroSD payload structure and binary mapping.
2026-07-09 Conecté todas las tierras, revisar si es correcta la conexión y distribución
    [Pico-Usb.kicad_pcb]
2026-07-09 Termine conexiones faltantes y trate de mejorar el ground
    [Pico-Usb.kicad_pcb]
2026-07-09 Corregi valores
    [Pico-Usb.kicad_sch]
2026-07-09 Limpieza: ignorar archivos generados de fabricación
2026-07-09 Corregi valores y pistas ground faltantes
    [Pico-Usb.kicad_pcb, Pico-Usb.kicad_sch]
2026-07-10 agregue texto de hola papus
    [Pico-Usb.kicad_pcb]
2026-07-10 Quite hola papus
    [Pico-Usb.kicad_pcb]
2026-07-10 Cambie el usb A
    [Pico-Usb.kicad_sch]
2026-07-10 se agrego el diseno del nombre del producto
    [Pico-Usb.kicad_pcb]
2026-07-10 Modifique los componentes originales por unos que si se encuentran
    [Pico-Usb.kicad_pcb, Pico-Usb.kicad_sch]
2026-07-10 Verifique una vez más conexiones
    [Pico-Usb.kicad_pcb]
2026-07-11 Enhance README with fallback note and visuals
    Updated tactical fallback note for clarity and added structured sections for hardware renders and PCB layout.
2026-07-11 Enhance Board Designs & Renders section in README
    Updated the section for Board Designs & Renders with improved formatting and added images for 3D and 2D layouts.
2026-07-11 Update README for clarity in board designs section
